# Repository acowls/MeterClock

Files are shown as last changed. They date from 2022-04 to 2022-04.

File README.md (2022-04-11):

# MeterClock

A clock displaying hour and minutes on two analog meters with a red LED matrix for time and date. Powered by an AVR Arduino and an RTC.

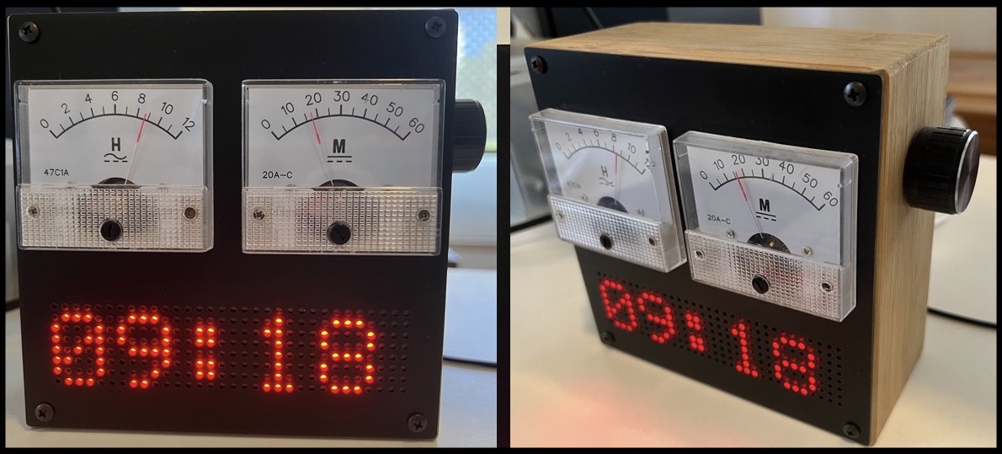
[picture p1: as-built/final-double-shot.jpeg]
final shot


## Parts List

+ Bamboo/Timber box without lid
+ Ardunino Nano (ATMega168)
+ milliamp meters x2
+ LED matrix modile 32 by 8 (4 module 8x8 LED matrix powered by MAX7221)
+ DS3231 module
+ PCB front panel
+ PCB inner meter panel x2 (one for hours, one for minutes)
+ Functional PCB
+ Push button
+ Rotary Encoder, with knob
+ various small screws for mounting

### Tools Required

+ Soldering Iron
+ Solder
+ Saw for cutting timber
+ Screwdrivers
+ Hot Glue Gun
+ Drill

## Design

I wanted the overall product to have a retro vibe to provide some symmetry with the meters. I chose a bamboo housing (which isn't exactly retro - maybe wood panelling would be more so - but is readily available in many discount thrift shops near me). So with the outer material chosen I then needed to think about the front panelling. I took the decision early on to use EasyEDA as the schematic design tool and JLCPCB as the manufacturer. As part of that approach I decided to make the front panel out of a PCB. This could be made on a 3D printer instead. The inner panels, those that sit inside the meters, are also made from a white PCB with black lattering. I do like the precision of the white PCB. Alternatively these could be made with paper and produced on a standard laser printer and cut to fit. 

One of the use cases I had for the clock is to softly alert me every hour and half hour during the day. This is my cue that I might have to join a meeting or otherwise check my schedule. The code turns the LED matrix on each half hour during daytime. 

### Power

Power for the device is 5V from the micro-USB connector extent on the Ardunio Nano module. This also serves as the programming port for updating the code. The board was oriented so that the micro USB was accessible from the rear of the encolsure. 

### Interface

The rotary control is used for changing date and time. I chose this interface method since it is much smoother and nicer than clicking buttons and in my opinion more intuitive. The code isnt that much more complex and I'd argue that the physcial build is simplified since one physcial encoder provides three inputs: up, down and click. The encoder has another advantage in mounting location. If you put buttons on the side of a device you need to hold the top of the device while pressing the buttons otherwise the device slips around. In practice this means using your other hand or using the thumb to hold it down while the fingers do the clicking. The one button I put on the device i mounted towards the top on the back panel. For usage you would look at the front of the device and then put your hand over the top and with your palm resting on the device click / hold the button down to enter the mode for setting the time and date.

Using 7H by 5W characters the 32x8 LED matrix provides enough space for the display for 5 characters at a time. This is sufficient for year, date and time. I originally intended to have animated use of the matrix (scrolling) but the max storage space of the ATMega168 was full.

### Improvements

I hit the limits of functionality that I could pack inside of the Arduino Nano ( an ATMega168 with 16k storage). With two buttons and a rotary dial plus the outputs of the 32x8 matrix and the two analgoue meters there is a fair bit more functionality I wanted to write but simply ran out of bytes of storage in the Arduino Nano to do so. Any improvements should look at using a controller with more storage space. 

### Schematic

The circuit is built around the Arduino Nano with debouncing circuitry for the mechanical inputs of the buttons & encoder. There are interfaces to the LED matrix module and the RTC module. 

The meters operate through a 2.7k ohm resister to ground and two pins on the Arudino supply the analog output (aka a variable voltage) to move the needles from 0 to 12 for the hours and 0 to 60 for the minutes.

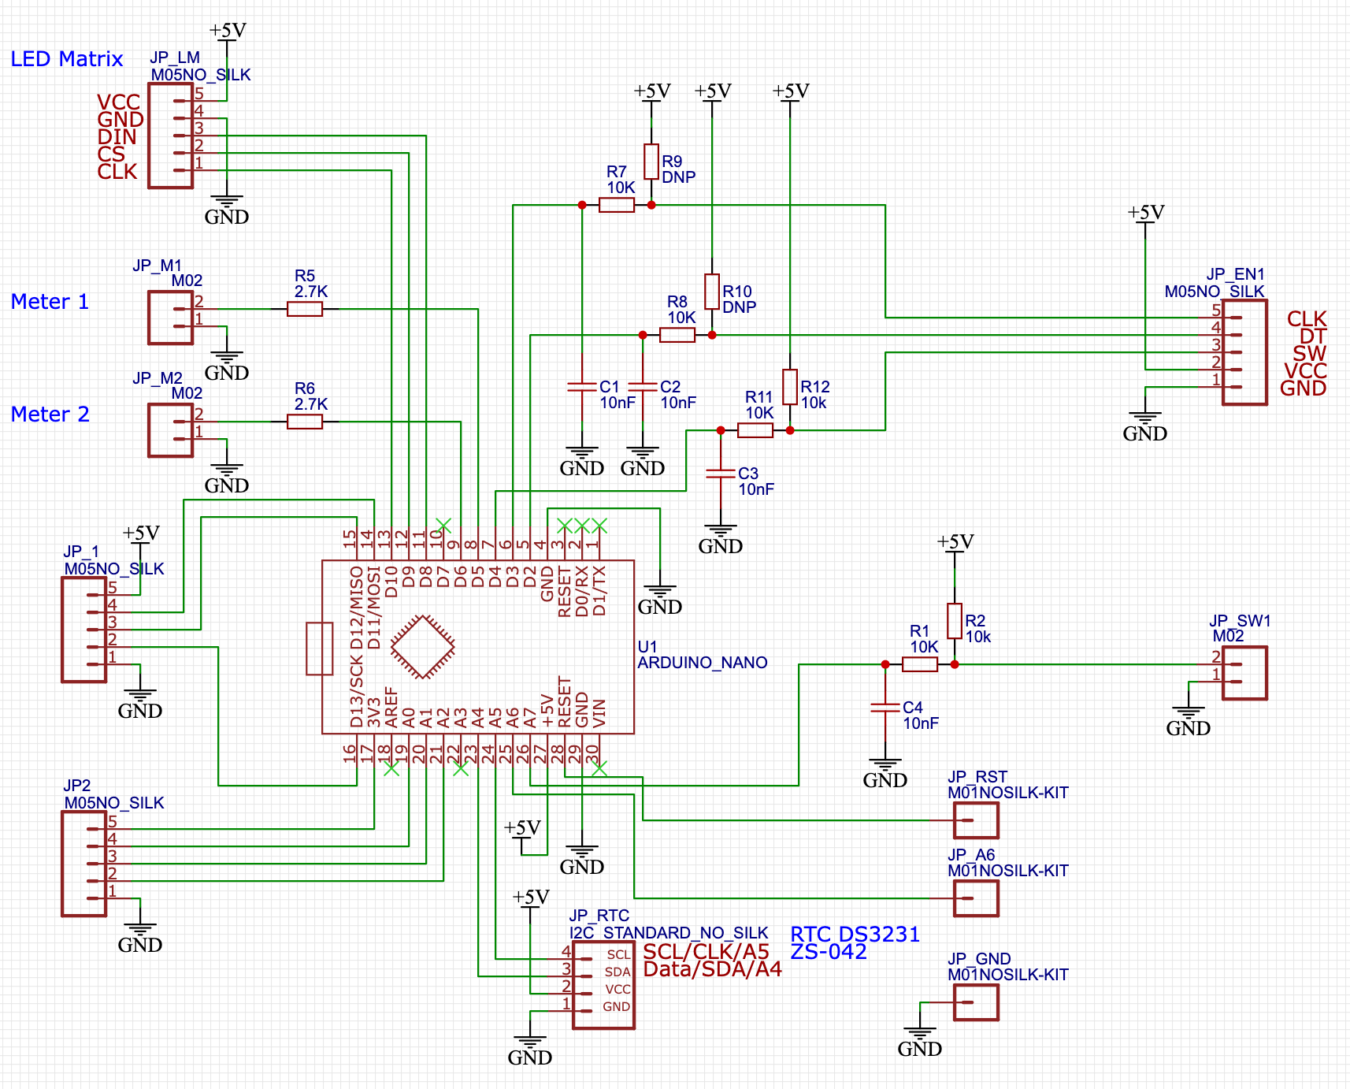
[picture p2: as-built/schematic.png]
schematic


## Software

### Library List

+ [Notched Shaft Encoder v1.0.0](https://github.com/lesterlo/Notched-Shaft-Encoder) - Monitor the postion and clickable button status from a notched shaft encoder
+ [RTCLib by NeiroNx v1.6](https://github.com/NeiroNx/RTCLib) - A library that makes interfacing DS1302, DS1307, DS3231, PCF8583, PCF8563, RTC_Millis Real Time Clock modules easy.
+ [AceButton v1.6.1](https://github.com/bxparks/AceButton) - An adjustable, compact, event-driven button library that handles debouncing and dispatches events to a user-defined event handler.

## As-Built

### External

Inside of the Meter Clock there is room for Arduino Nano, DS3231 module, connectors for LED matrix 32x8 using MAX7221 and debouncing connection for two switches and one encoder.

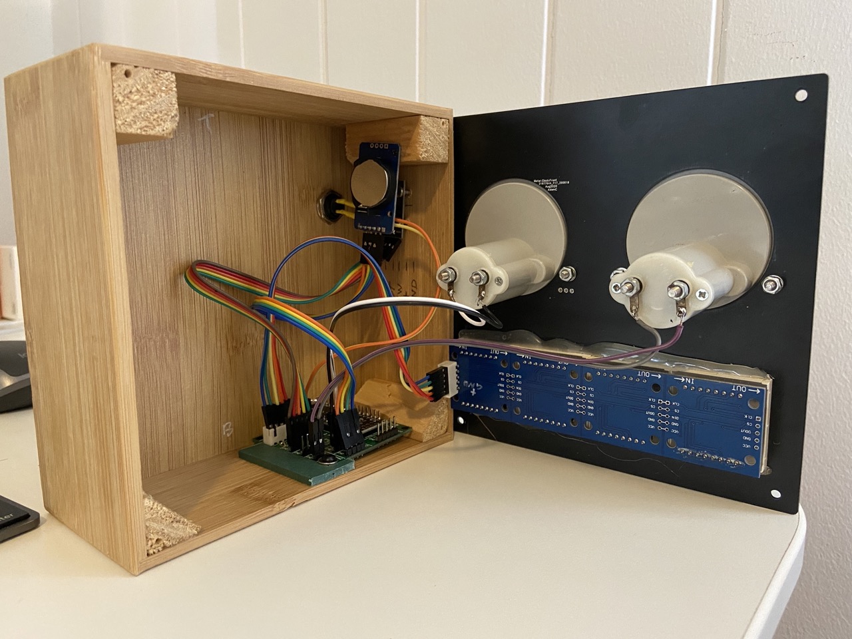
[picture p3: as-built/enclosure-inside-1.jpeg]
inside of the meter clock


### PCB Mainboard 

This is the PCB inside of the meter clock. It has a spot to mount the Arduino Nano and the RTC. The remainder of the board has connectors to the display (led matrix) and the RC filtered inputs (encoder and push button). 

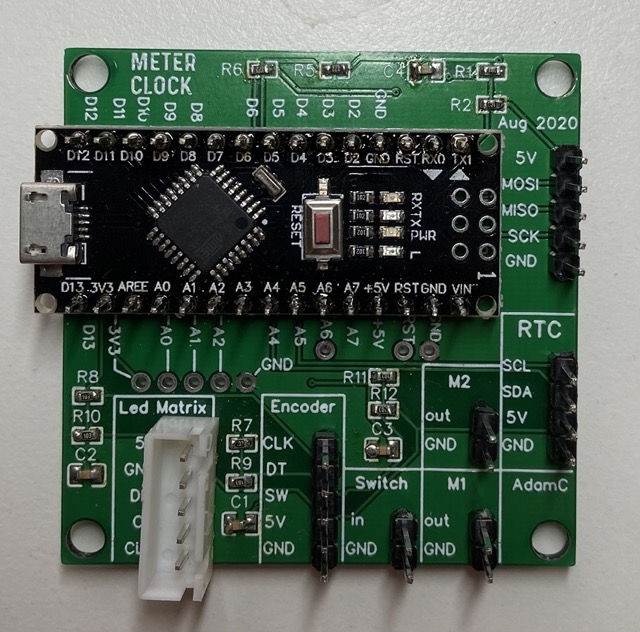
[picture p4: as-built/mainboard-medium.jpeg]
mainboard with adruino nano mounted


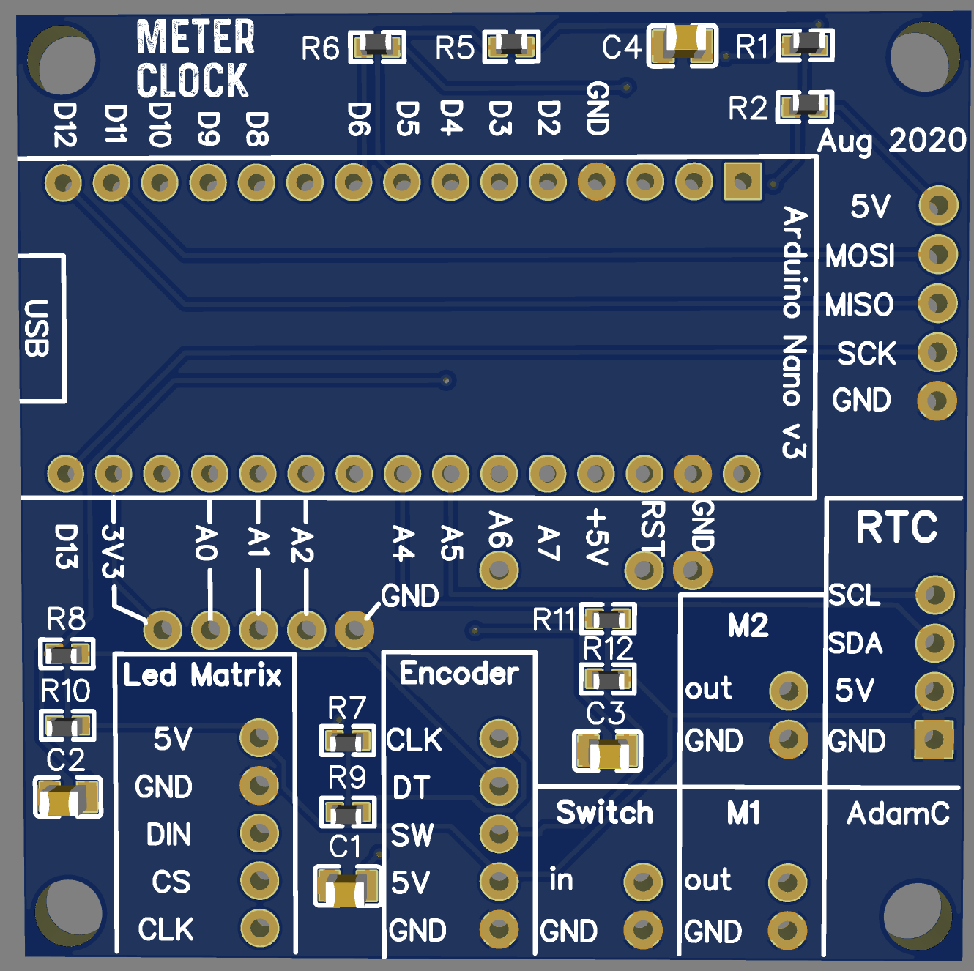
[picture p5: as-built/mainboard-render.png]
mainboard


### PCB Inside Meter

MeterClockInner - The inside of the analogue meters that shows graduations from 0 to 12 for hours and on the reverse side, from 0 to 60 for minutes.
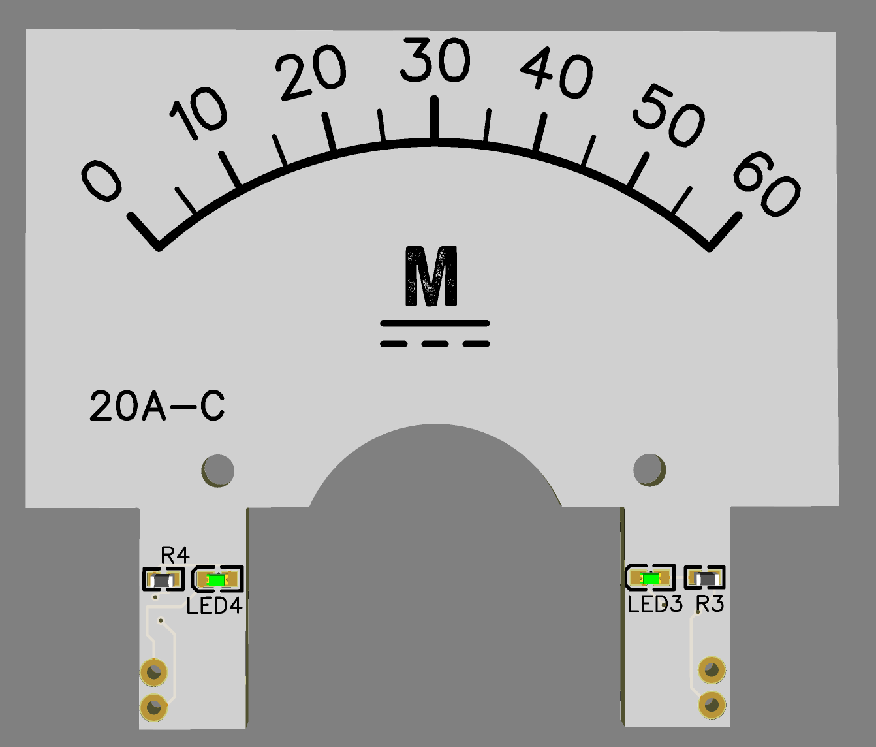
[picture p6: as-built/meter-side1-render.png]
inside pcb


+ [oshwlab MeterClockInner](https://oshwlab.com/adamc/meterclockinner)
+ [EasyEDA MeterClockInner](https://easyeda.com/editor#id=60065c9caff1483fb72fd92636a5c24b)

### PCB Front Face

to do

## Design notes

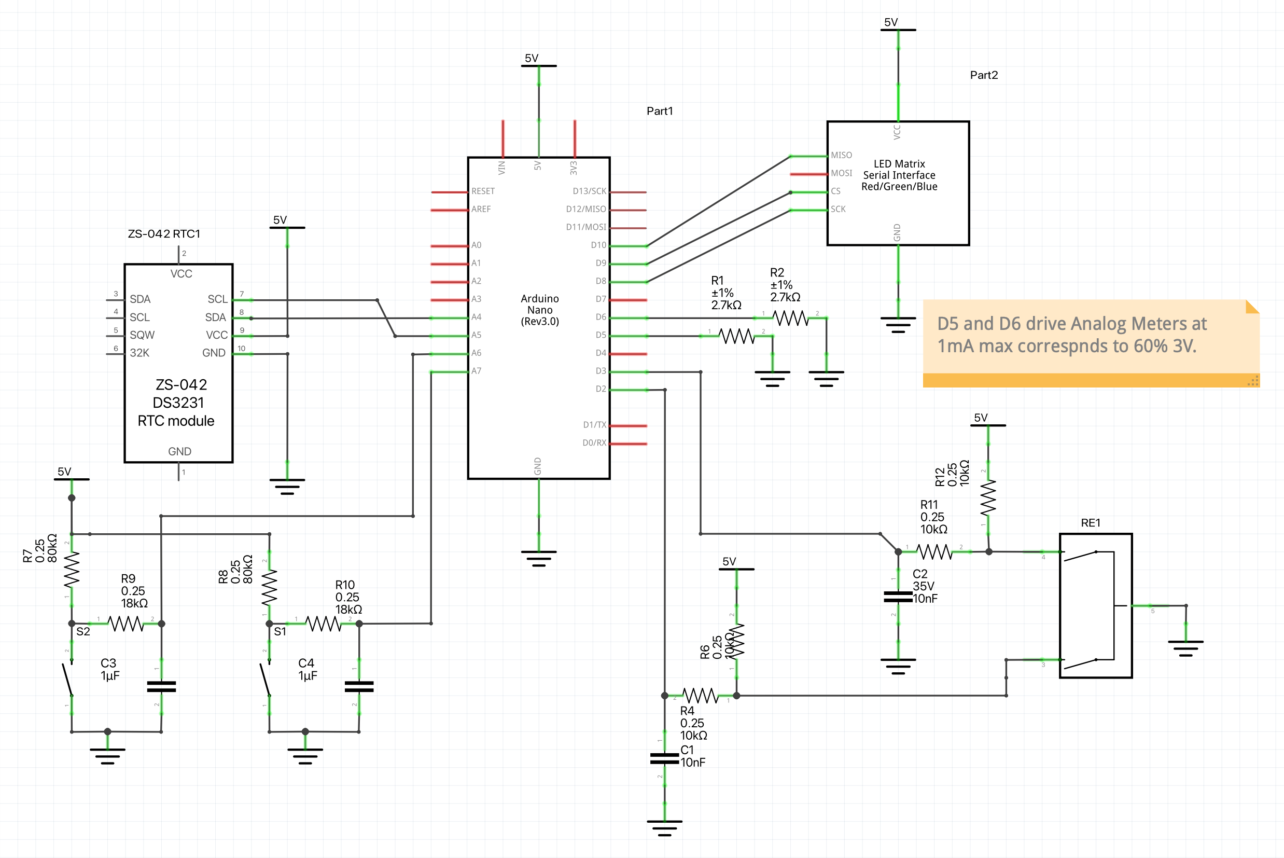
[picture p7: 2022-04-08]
as-built/fritzing-schematic.png

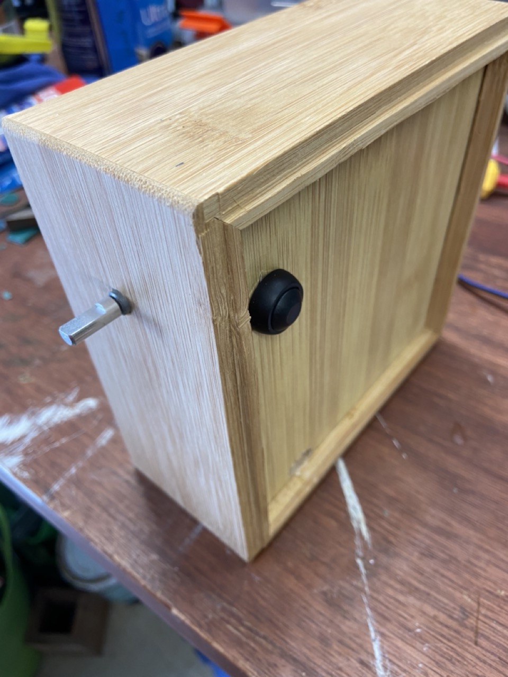
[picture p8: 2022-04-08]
as-built/enclosure-rear-2.jpeg

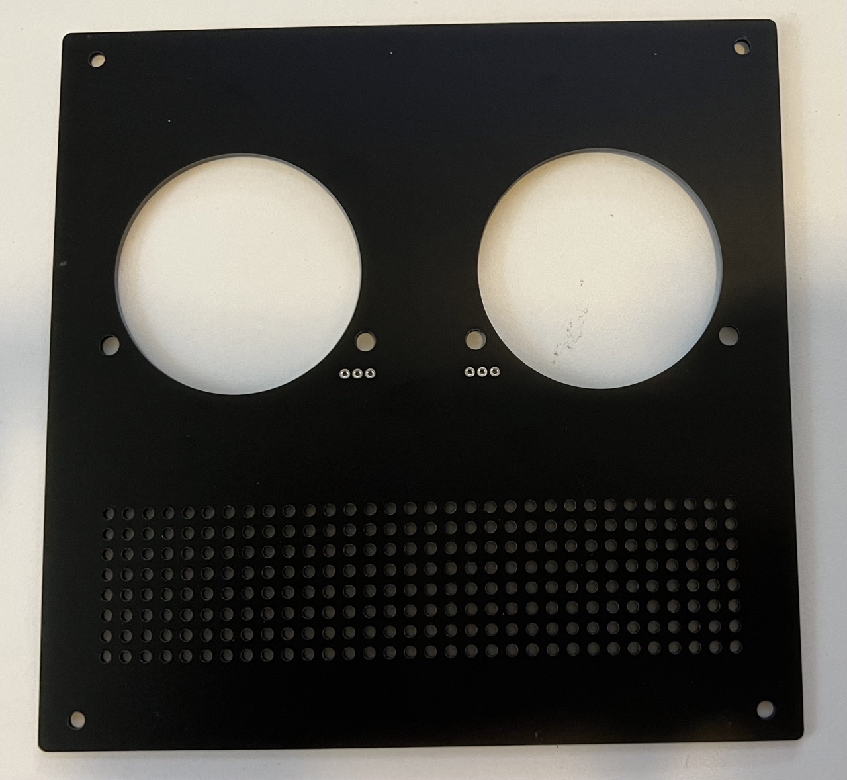
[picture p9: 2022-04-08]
as-built/front-panel.jpeg

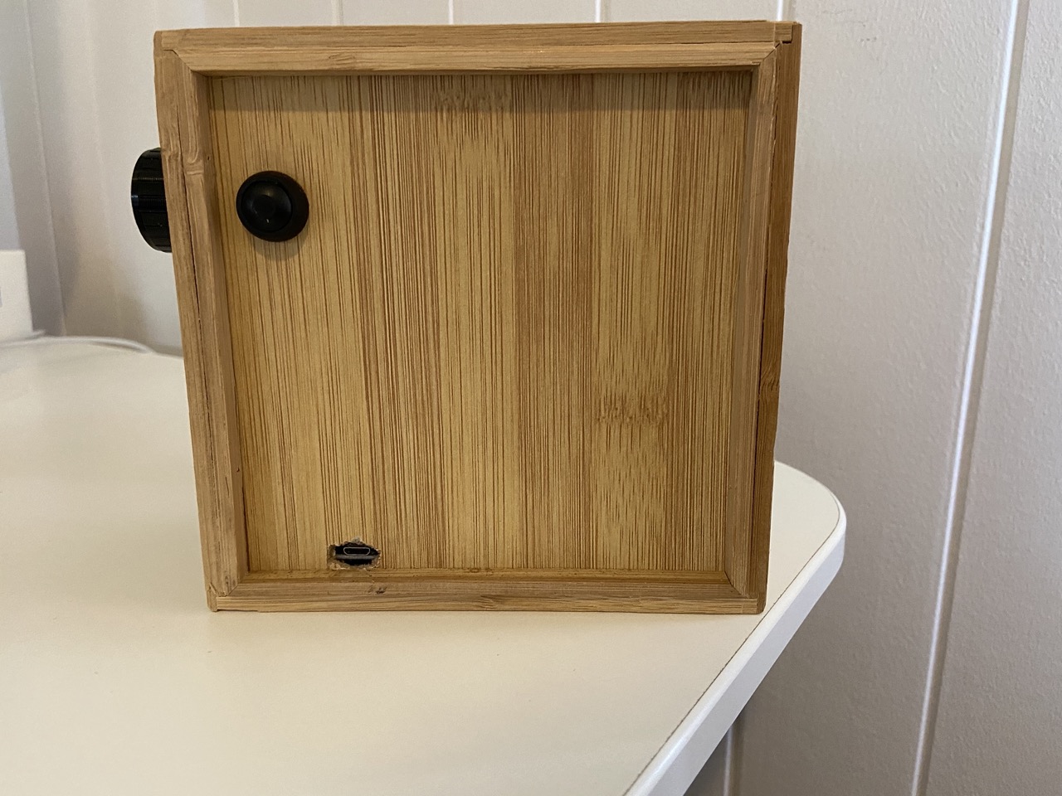
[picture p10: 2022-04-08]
as-built/enclosure-rear-1.jpeg

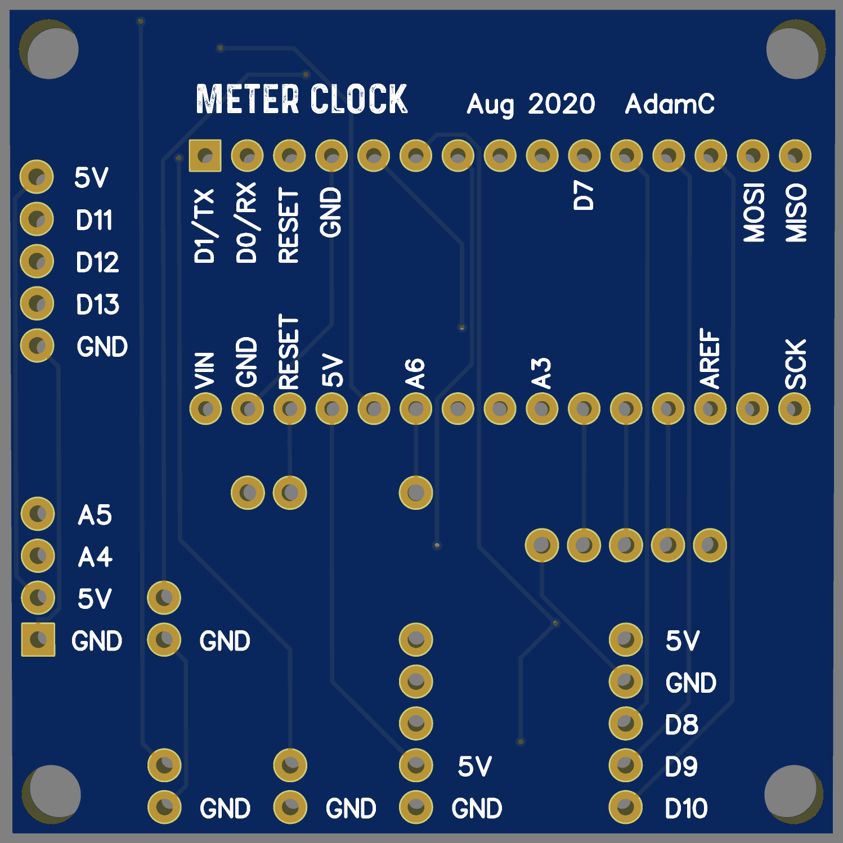
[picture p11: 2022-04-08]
as-built/mainboard-rear-render.png

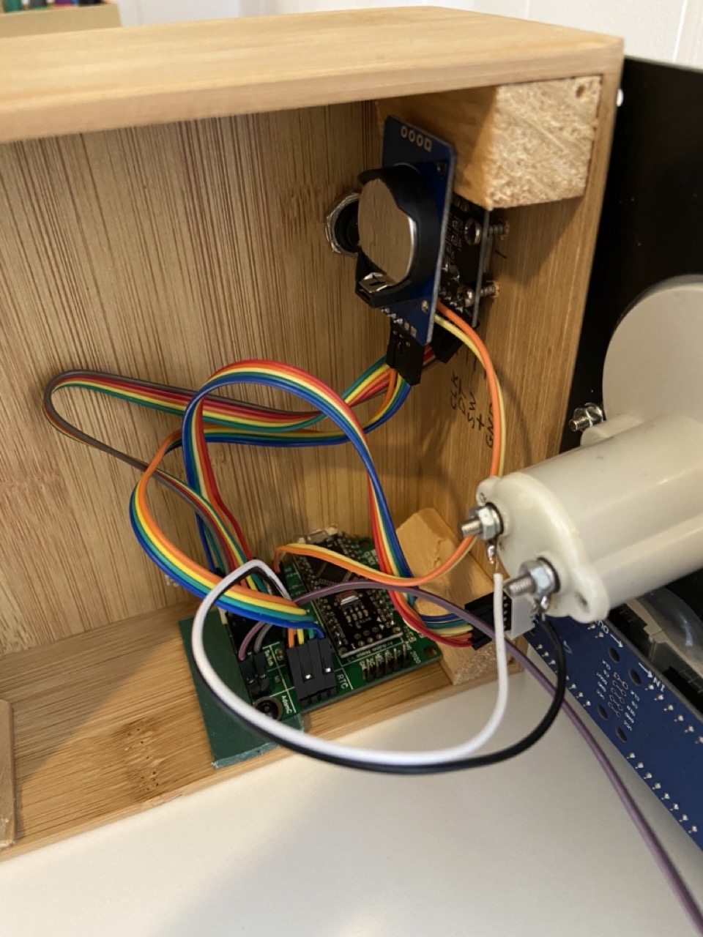
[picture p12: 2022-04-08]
as-built/enclosure-inside-2.jpeg

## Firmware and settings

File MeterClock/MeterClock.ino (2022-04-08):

#include "LedMatrixControlEx.h"
#include "RTClib.h" // https://github.com/NeiroNx/RTCLib/blob/master/src/RTClib.h
#include <NSEncoder.h>
#include <AceButton.h>
using namespace ace_button;
// fancy text from https://textfancy.com/multiline-text-art/

///// INPUTS
// Encoder with push button  switch
// Pushbutton Switch

///// OUTPUTS
// 2x Analog Meters showing Hours and Minutes
// 4x LEDs for back lighting those two Meters
// 32x8 LED matrix for display of characters and words

///// FEATUREs
// Backlighting on (for night time)
// Meter Time always on
// Toggle through timezones (no daylight saving?)
//   - Date programmed through USB
// Set Hour
// Set Minutes 

///// General Approach
// B2-LP Long Hold back button #2 to enter time / date setting mode.
//  Hour Set  B1-C > Minute Set 1C > Year Set 1C> Month Set
//  2C > cancel ... go to display 
//  2L > save new date and time 


// RTC 3231
// Defaults to:
// SCL/CLK  on A5 (pin 24)
// SCA/DATA on A4 (pin 23)
RTC_DS3231 rtc;

// NSEncoder (S1, S2, # pulses / notch)
// CLK = D3 (pin 6)
// CLK = D2 (pin 5)
NSEncoder control(2, 3, 2);

const byte MODULE_COUNT = 4;
// LedMatrixControl ( DIN, CLK, CS, # of 8x8s )
// DIN = D8 (pin 11) 
// CS  = D9 (pin 12)
// CLK = D10 (pin 13)
LedMatrixControl lc = LedMatrixControl(8, 10, 9, MODULE_COUNT);

// Diplay Meters
#define METER_HOUR   5
#define METER_MINUTE 6

// Buttons
// D4 (pin 7)
// A2 (pin 2?)
#define BUTTON1_PIN 4
#define BUTTON2_PIN A2

AceButton button1(BUTTON1_PIN);
AceButton button2(BUTTON2_PIN);

void handleEvent(AceButton*, uint8_t, uint8_t);

int currentPosInFrameBuffer = 0;
int controlPosition  = 0;

// Milliseconds between frames in animation effects
#define QUICK_STEP 15
// Maximum number of characters in the buffer
#define MAX_CHARS_IN_BUFFER 10

void setup(){
  delay(1000); // some boards reboot twice
  Serial.begin(115200);

  // Buttons use the built-in pull up register.
  pinMode(BUTTON1_PIN, INPUT_PULLUP);
  pinMode(BUTTON2_PIN, INPUT_PULLUP);

  ButtonConfig* buttonConfig = ButtonConfig::getSystemButtonConfig();
  buttonConfig->setEventHandler(handleEvent);
  buttonConfig->setEventHandler(handleEvent);
  buttonConfig->setFeature(ButtonConfig::kFeatureClick);
  buttonConfig->setFeature(ButtonConfig::kFeatureDoubleClick);
  buttonConfig->setFeature(ButtonConfig::kFeatureLongPress);
  
  // set the intensity
  lc.setIntensity(3);
  lc.shutdown(0);

    if (! rtc.begin()) {
    Serial.println(F("Couldn't find RTC"));
    Serial.flush();
    abort();
  }

  if (rtc.lostPower()) {
    Serial.println(F("RTC lost power, let's set the time!"));
    // When time needs to be set on a new device, or after a power loss, the
    // following line sets the RTC to the date & time this sketch was compiled
    rtc.adjust(DateTime(F(__DATE__), F(__TIME__)));
    // This line sets the RTC with an explicit date & time, for example to set
    // 15th Oct 2020 - 12:45:55
    // rtc.adjust(DateTime(2020, 10, 15, 12, 40, 55));
  }

  welcome_sequence();
}

// counter of how many times through the loop since lat mode change or input
uint16_t tick = 0;

void loop() {
  int newPos;
  
  if (control.get_Position(newPos)) {
    char posfmt[8];
    snprintf(posfmt, 8, "%d", newPos);
    Serial.println(posfmt);

    // reset the tick on input
    tick = 0;

    // call the correct handler for each event type
    if (newPos - controlPosition > 0) {
      if (handle_encoder_down(controlPosition, newPos))
        controlPosition = newPos;
      }
    else {
      if (handle_encoder_up(controlPosition, newPos))
        controlPosition = newPos;        
      }
    lc.updateDisplay();    
  }
  button1.check();
  button2.check();

  doTimer(tick);
  tick = tick + 1;
  doDisplay();
  doWakeEachHalfHour();
  delay(20);

}


/*
** The event handler for both buttons.
*/
void handleEvent(AceButton* button, uint8_t eventType, uint8_t buttonState) {
    switch (eventType) {
      case AceButton::kEventClicked:
        Serial.print(F("Click on Button "));
        if (button->getPin() == BUTTON1_PIN) {
          Serial.println(F("1 encoder button")); 
          handle_button_click();
        }
        else {
          Serial.println(F("2 rear button")); 
          handle_button_rear_click();
        }
        // reset the tick on input
        tick = 0;        
        break;

      // LONG PRESS BUTTON 1  
      case AceButton::kEventLongPressed:
        Serial.print(F("Long Press on Button "));       
        
        if (button->getPin() == BUTTON1_PIN) {
          Serial.println(F("1 encoder button")); 
          handle_button_longpress();
        }
        else {
          Serial.println(F("2 rear button")); 
          handle_button_rear_longpress();
        }
        // reset the tick on input
        tick = 0;
        break;
    }
}

//      *************************
//          M O D E   B I T s
//      *************************
#define MODE_POWERUP       0x4000

#define MODE_DISPLAY       0x0100 // mask for the following :-
#define MODE_DISPLAY_HOMI  0x0101  // hours and minutes
#define MODE_DISPLAY_DATE  0x0102  // Month/Day, eg: 30/11
#define MODE_DISPLAY_YEAR  0x0104  // year,      eg: 2020
#define MODE_DISPLAY_SLEEP 0x0180  // display off

#define MODE_SET_DT        0x0200 // mask for the following :-
#define MODE_SET_DT_HOUR   0x0201
#define MODE_SET_DT_MIN    0x0202
#define MODE_SET_DT_YEAR   0x0204
#define MODE_SET_DT_MON    0x0208
#define MODE_SET_DT_DAY    0x0210

uint16_t master_mode = MODE_POWERUP;
#define ISMODE(m) (master_mode & m) == m

const TimeSpan oneDay =   TimeSpan(1, 0, 0, 0);
const TimeSpan oneHour =  TimeSpan(0, 1, 0, 0);
const TimeSpan oneMin =   TimeSpan(0, 0, 1, 0);

DateTime editableDateTime;

/*
 * set the MODE
 * use this function instead of attempting to set mode variable directly. 
 * This will reset tick counter on a mode change.
 */
void setMode(uint16_t newMode) {
  if (master_mode != newMode) {
    Serial.print(F("setMode 0x"));
    Serial.print(master_mode, HEX);
    Serial.print(F("  to  0x"));
    Serial.println(newMode, HEX);    
    master_mode = newMode;
    // reset tick counter back to zero 
    tick = 0;
  }
}

/*
 * 
 *   o-o   o-O-o  o-o  o--o  o      O  o   o 
 *   |  \    |   |     |   | |     / \  \ /  
 *   |   O   |    o-o  O--o  |    o---o  O   
 *   |  /    |       | |     |    |   |  |   
 *   o-o   o-O-o o--o  o     O---oo   o  o   
 *                                       
 * do DISPLAY
 * the correct thing based on the current mode.
 */
void doDisplay() {
  char textbuf[8];

  if (ISMODE(MODE_DISPLAY)) {
    DateTime now = rtc.now();

    setMeters(now.hour(), now.minute());
    
    if (ISMODE(MODE_DISPLAY_SLEEP)) {
      lc.clearDisplay();
      // exit without an update
      return;
    }
    else if (ISMODE(MODE_DISPLAY_HOMI))
      snprintf(textbuf, 8, "%02d:%02d", now.hour(), now.minute()); 
    else if (ISMODE(MODE_DISPLAY_DATE))
      snprintf(textbuf, 8, "%02d/%02d", now.day(), now.month()); 
    else if (ISMODE(MODE_DISPLAY_YEAR))
      snprintf(textbuf, 8, "%04d", now.year());
  }
  else if (ISMODE(MODE_SET_DT_HOUR)) {
    if (((tick / 20) % 2) == 0)
      snprintf(textbuf, 8, "%02d:%02d", editableDateTime.hour(), editableDateTime.minute());     
    else
      snprintf(textbuf, 8, "  :%02d", editableDateTime.minute());
    setMeters(editableDateTime.hour(), editableDateTime.minute());         
  }
  else if (ISMODE(MODE_SET_DT_MIN)) {
    if (((tick / 20) % 2) == 0)
      snprintf(textbuf, 8, "%02d:%02d", editableDateTime.hour(), editableDateTime.minute());     
    else
      snprintf(textbuf, 8, "%02d:  ", editableDateTime.hour());      
    setMeters(editableDateTime.hour(), editableDateTime.minute()); 
    }
  else if (ISMODE(MODE_SET_DT_DAY)) {
    if (((tick / 20) % 2) == 0)
      snprintf(textbuf, 8, "%2d/%02d", editableDateTime.day(), editableDateTime.month());     
    else
      snprintf(textbuf, 8, "  /%02d", editableDateTime.month());      
  }   
  else if (ISMODE(MODE_SET_DT_MON)) {
    if (((tick / 20) % 2) == 0)
      snprintf(textbuf, 8, "%2d/%02d", editableDateTime.day(), editableDateTime.month());     
    else
      snprintf(textbuf, 8, "%2d/  ", editableDateTime.day());      
  }
  else if (ISMODE(MODE_SET_DT_YEAR)) {
    snprintf(textbuf, 8, "Y%04d", editableDateTime.year());      
    
  }
    
  putWordInBuffer(textbuf);
  lc.updateDisplay();     
}


void doWakeEachHalfHour() {
  // wake display on the hour every hour
  if (ISMODE(MODE_DISPLAY_SLEEP)) {
    DateTime now = rtc.now();
    if (now.second() == 0 && (now.minute() == 0 || now.minute() == 30)) {
      setMode(MODE_DISPLAY_HOMI);
    }
  }
}
/**
 *   ___         __  __  
 *    |  | |\/| |_  |__) 
 *    |  | |  | |__ | \  
 *                   
 *   Actions taken based on how many times through the loop we have traversed 
 */
int doTimer(uint16_t ticks)
{
  // check if in POWERUP explicitly 
  if (ISMODE(MODE_POWERUP)) {
    if (ticks > 100)
      setMode(MODE_DISPLAY_HOMI);
  }
  // screen idle time
  else if (ISMODE(MODE_DISPLAY)) {
    if (ticks > 500)
      setMode(MODE_DISPLAY_SLEEP);
    }
  // timeout on setting the date and time
  else if (ISMODE(MODE_SET_DT)) {
    if (ticks > 500)
      setMode(MODE_DISPLAY_HOMI);
  }
}


/*
 *  __  ____ __   __      __  _  _ ___ ___  __  _  _    _     __  _  _  ___     __   __  ____  ___  ___
 * |__/ |___|__| |__/    |__] |  |  |   |  |  | |\ |    |    |  | |\ | | __    |__] |__/ |___ [__  [__ 
 * |  \ |___|  | |  \    |__] |__|  |   |  |__| | \|    |___ |__| | \| |__]    |    |  \ |___ ___] ___]
 */
void handle_button_rear_longpress() {
  char textbuf[8];
  snprintf(textbuf, 8, "hour"); 
      
  if (ISMODE(MODE_DISPLAY) || ISMODE(MODE_POWERUP)) {
    // enter date and time setting mode
    editableDateTime = rtc.now();
    setMode(MODE_SET_DT_HOUR);

    putWordInBuffer("set");
    lc.updateDisplay();
    delay(QUICK_STEP);
    putWordInBuffer("hour");
    lc.updateDisplay();
    
  } 
  else if (ISMODE(MODE_SET_DT)) {
    // end date and time setting mode. 
    rtc.adjust(editableDateTime);
    setMode(MODE_DISPLAY_HOMI);
        
    Serial.print(F("adjustment done "));
    Serial.print(editableDateTime.year());
    Serial.print(F("-"));
    Serial.print(editableDateTime.month());
    Serial.print(F("-"));
    Serial.print(editableDateTime.day());
    Serial.print(F(" "));
    Serial.print(editableDateTime.hour());
    Serial.print(F("h "));
    Serial.print(editableDateTime.minute());
    Serial.println(F("m"));
  }
  else
  {
    Serial.print(F("mode 0x"));
    Serial.print(master_mode, HEX);
    Serial.println(F(" unhandled in handle_button_rear_longpress()"));
  }
}

/*
 *     __  _  _ ___ ___  __  _  _    _     __  _  _  ___     __   __  ____  ___  ___
 *    |__] |  |  |   |  |  | |\ |    |    |  | |\ | | __    |__] |__/ |___ [__  [__ 
 *    |__] |__|  |   |  |__| | \|    |___ |__| | \| |__]    |    |  \ |___ ___] ___]
 */
void handle_button_longpress() {
  Serial.print(F("mode 0x"));
  Serial.print(master_mode, HEX);
  Serial.println(F(" unhandled in handle_button_longpress()"));
}

/*
 * handle REAR BUTTON click
 */
void handle_button_rear_click() {
  //
  handle_button_click();
  /*
    Serial.print(F("mode 0x"));
    Serial.print(master_mode, HEX);
    Serial.println(F(" unhandled in handle_button_rear_click"));
  */
}

/*
 * handle BUTTON click
 */
void handle_button_click() {
  if (ISMODE(MODE_SET_DT_HOUR)) {
    setMode(MODE_SET_DT_MIN);
  }  
  else if (ISMODE(MODE_SET_DT_MIN)) {
    setMode(MODE_SET_DT_YEAR);
  } 
  else if (ISMODE(MODE_SET_DT_YEAR)) {
    setMode(MODE_SET_DT_MON);
  } 
  else if (ISMODE(MODE_SET_DT_MON)) {
    setMode(MODE_SET_DT_DAY);
  } 
  else if (ISMODE(MODE_SET_DT_DAY)) {
    setMode(MODE_SET_DT_HOUR);
  }
  else {
    Serial.print(F("mode 0x"));
    Serial.print(master_mode, HEX);
    Serial.println(F(" unhandled in handle_button_click()"));
  }
}
                                                                       
                                                                        

/**
 *  _____               _            __ __ _____ 
 * |   __|___ ___ ___ _| |___ ___   |  |  |  _  |
 * |   __|   |  _| . | . | -_|  _|  |  |  |   __|
 * |_____|_|_|___|___|___|___|_|    |_____|__|   
 *
 * Handle ENCODER UP 
 * return 1 to allow click up
 */
bool handle_encoder_up(int current, int proposed) {
    /*char posfmt[8];
    snprintf(posfmt, 8, "%xu%d",master_mode, proposed); 
    Serial.println(posfmt);
    */

  if (ISMODE(MODE_DISPLAY_SLEEP)) {
    setMode(MODE_DISPLAY_HOMI);    
  }
  else if (ISMODE(MODE_DISPLAY_HOMI)) {
    setMode(MODE_DISPLAY_YEAR);    
  }
  else if (ISMODE(MODE_DISPLAY_DATE)) {
    setMode(MODE_DISPLAY_HOMI);    
  }
  else if (ISMODE(MODE_DISPLAY_YEAR)) {
    setMode(MODE_DISPLAY_DATE);    
  }
  else if (ISMODE(MODE_SET_DT_HOUR)) {
    editableDateTime = editableDateTime + oneHour; 
  }
  else if (ISMODE(MODE_SET_DT_MIN)) {
    editableDateTime = editableDateTime + oneMin;
  }
  else if (ISMODE(MODE_SET_DT_DAY)) {
    editableDateTime = editableDateTime + oneDay;
  }   
  else if (ISMODE(MODE_SET_DT_MON)) {
    int newMonth = editableDateTime.month() + 1;
    editableDateTime = DateTime(editableDateTime.year(), newMonth == 13 ? 0 : newMonth, editableDateTime.day(), editableDateTime.hour(), editableDateTime.minute(), 0);
  }
  else if (ISMODE(MODE_SET_DT_YEAR)) {
    int year = editableDateTime.year();
    if (year < 2150)
      editableDateTime = DateTime(year + 1, editableDateTime.month(), editableDateTime.day(), editableDateTime.hour(), editableDateTime.minute(), 0);
  }   
  else
  {
    Serial.print(F("mode 0x"));
    Serial.print(master_mode, HEX);
    Serial.println(F(" unhandled in handle_encoder_up()"));
  }
        
  return true;
}


/**
 *  _____               _            ____  _____ _ _ _ _____ 
 * |   __|___ ___ ___ _| |___ ___   |    \|     | | | |   | |
 * |   __|   |  _| . | . | -_|  _|  |  |  |  |  | | | | | | |
 * |_____|_|_|___|___|___|___|_|    |____/|_____|_____|_|___|
 *                                                           
 * Handle ENCODER DOWN
 * return 1 to allow click down
 */
bool handle_encoder_down(int current, int proposed) {
    /*char posfmt[8];
    snprintf(posfmt, 8, "%xd%d",master_mode, proposed); 
    Serial.println(posfmt);
    */
    
  if (ISMODE(MODE_SET_DT_HOUR)) {
    editableDateTime = editableDateTime - oneHour;
    }
  else if (ISMODE(MODE_SET_DT_MIN)) {
    editableDateTime = editableDateTime - oneMin;
    }
  else if (ISMODE(MODE_SET_DT_DAY)) {
    editableDateTime = editableDateTime - oneDay;
    }    
  else if (ISMODE(MODE_SET_DT_MON)) {
    int newMonth = editableDateTime.month() - 1;
    editableDateTime = DateTime(editableDateTime.year(), newMonth == 0 ? 12 : newMonth, editableDateTime.day(), editableDateTime.hour(), editableDateTime.minute(), 0);
    }
  else if (ISMODE(MODE_SET_DT_YEAR)) {
    int year = editableDateTime.year();
    if (year > 2020)
      editableDateTime = DateTime(year - 1, editableDateTime.month(), editableDateTime.day(), editableDateTime.hour(), editableDateTime.minute(), 0);
    }    
  else if (ISMODE(MODE_DISPLAY_SLEEP)) {
    setMode(MODE_DISPLAY_HOMI);    
  }
  else if (ISMODE(MODE_DISPLAY_HOMI)) {
    setMode(MODE_DISPLAY_DATE);    
  }
  else if (ISMODE(MODE_DISPLAY_DATE)) {
    setMode(MODE_DISPLAY_YEAR);    
  }
  else if (ISMODE(MODE_DISPLAY_YEAR)) {
    setMode(MODE_DISPLAY_HOMI);    
  }
  else    
  {    
    Serial.print(F("mode 0x"));
    Serial.print(master_mode, HEX);
    Serial.println(F(" unhandled in handle_encoder_down()"));
  }
              
  return true;
}


/*
 * set the meter displays
 */
void setMeters(uint8_t hour, uint8_t minute) {
  // HOUR Needle    0 = 0, 140 == 12 (full extent)
  // Minute Needle  0 = 0, 68  == 30 (half extent)
  
  // special case where we leave it at the right hand extent of the hour 
  if (hour == 12 && minute == 0) {
    analogWrite(METER_HOUR, 12 * 140 / 12);
  }
  else if (hour > 12) 
  {
    analogWrite(METER_HOUR, (hour - 12)  * 140 / 12);
  }
  else {
    analogWrite(METER_HOUR, hour * 140 / 12);
  }
  // set minute
  analogWrite(METER_MINUTE, minute * 68 / 30);  
}


/*
 * Welcome Sequence
 */
void welcome_sequence(){
  putWordInBuffer("Hello");
  lc.updateDisplay();

  DateTime now = rtc.now();
  char timefmt[8];
  snprintf(timefmt, 8, "%02d:%02d", now.hour(), now.minute());
  putWordInUpperBuffer(timefmt);
  annimateLedMatrixDown(500, QUICK_STEP, 500);  
}

/**
 * Animate characters in buffer to the left - slide effect. 
 */
void annimateLedMatrixLeft(int preDelay, int stepDelay, int postDelay) {
  delay(preDelay);
  if (currentPosInFrameBuffer > MODULE_COUNT * 8 - 5) {
    for (int loop = 0; loop < 6; loop++) {
      lc.shiftLeftFrameBuffer();            
      delay(stepDelay);
      lc.updateDisplay();
    }
    delay(postDelay);
  }
}

/**
 * Animate from Upper to Display buffer - window wipe down effect.
 */
void annimateLedMatrixDown(int preDelay, int stepDelay, int postDelay) {
  delay(preDelay);
  for (int loop = 0; loop < 8; loop++) {
    delay(stepDelay);
    lc.shuffleDownFrameBuffer();            
    lc.updateDisplay();
  }
  delay(postDelay);
}

/**
 * Animate from Upper to Display buffer - window wipe up effect.
 */
void annimateLedMatrixUp(int preDelay, int stepDelay, int postDelay) {
  delay(preDelay);
  for (int loop = 0; loop < 8; loop++) {
    delay(stepDelay);
    lc.shuffleUpFrameBuffer();            
    lc.updateDisplay();
  }
  delay(postDelay);
}

/**
 * Put a word in the Upper buffer
 */
void putWordInUpperBuffer(char *theWord)
{
  lc.clearUpperFrameBuffer();
  int len = strlen(theWord);
  if (len < 0 || len > MAX_CHARS_IN_BUFFER)
     return;
    
  for (int i = 0; i < len; i++)
  {
    lc.drawCharInUpperFrameBuffer(i * 6, theWord[i]);
  }
}

/**
 * Put a word in the Lower buffer
 */
void putWordInLowerBuffer(char *theWord)
{
  lc.clearLowerFrameBuffer();
  int len = strlen(theWord);
  if (len < 0 || len > MAX_CHARS_IN_BUFFER)
     return;
    
  for (int i = 0; i < len; i++)
  {
    lc.drawCharInLowerFrameBuffer(i * 6, theWord[i]);
  }
}

/**
 * Put a word in to the main display buffer
 */
void putWordInBuffer(const char *theWord)
{
  lc.clearFrameBuffer();
  int len = strlen(theWord);
  if (len < 0 || len > MAX_CHARS_IN_BUFFER)
     return;
    
  for (int i = 0; i < len; i++)
  {
    lc.drawCharInFrameBuffer(i * 6, theWord[i]);
  }
}

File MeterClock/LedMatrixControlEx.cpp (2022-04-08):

#include "LedMatrixControlEx.h"

// these are the opcodes for the MAX7221 and MAX7219 - refer datasheet
#define OP_NOOP   0
#define OP_DIGIT0 1
#define OP_DIGIT1 2
#define OP_DIGIT2 3
#define OP_DIGIT3 4
#define OP_DIGIT4 5
#define OP_DIGIT5 6
#define OP_DIGIT6 7
#define OP_DIGIT7 8
#define OP_DECODEMODE  9
#define OP_INTENSITY   10
#define OP_SCANLIMIT   11
#define OP_SHUTDOWN    12
#define OP_DISPLAYTEST 15

#define BUFFER_MAIN 0
#define BUFFER_UPPER 1
#define BUFFER_LOWER 2

#include <stdarg.h>
void printout(const char *fmt, ...) {
  #if 0
  char buf[128]; // resulting string limited to 128 chars
  va_list args;
  va_start(args, fmt);
  vsnprintf(buf, 128, fmt, args);
  va_end(args);
  Serial.print(buf);
  #endif
}

LedMatrixControl::LedMatrixControl(int dataPin, int clkPin, int csPin, int numModules) 
{
    SPI_MOSI=dataPin;
    SPI_CLK=clkPin;
    SPI_CS=csPin;

    // always at most 8 matrix modules.
    if (numModules <= 0 || numModules > MAX_MAX_MODULES )
        numModules = MAX_MAX_MODULES;

    maxModules = numModules;
    pinMode(SPI_MOSI, OUTPUT);
    pinMode(SPI_CLK, OUTPUT);
    pinMode(SPI_CS, OUTPUT);
    digitalWrite(SPI_CS, HIGH);

    // turn any display 'testing' OFF by sending a zero 
    spiTransferToAll("DISPLAYTEST", OP_DISPLAYTEST, 0);
    // scanlimit is set to the maximum (value 7) which is for 8 "digits", where a digit is the 7-seg LED. <-- this is a bit confusing but trust me.
    spiTransferToAll("SCANLIMIT", OP_SCANLIMIT, 7);
    // for 8x8 LED matrix modules we want all decoding done by use as we are not dealing with 7-seg LEDs
    spiTransferToAll("DECODEMODE", OP_DECODEMODE, 0);
    // clear the display
    clearDisplay();
    // now we get out of shutdown-mode on startup
    spiTransferToAll("SHUTDOWN", OP_SHUTDOWN, 0);
}

int LedMatrixControl::getModuleCount() {
    return maxModules;
}

void LedMatrixControl::shutdown(bool b) 
{
    if (b)
      spiTransferToAll("SHUTDOWN", OP_SHUTDOWN, 0);
    else
      spiTransferToAll("SHUTDOWN", OP_SHUTDOWN, 1);
}

void LedMatrixControl::setIntensity(int intensity) 
{
    if (intensity >= 0 && intensity < 16) 
      spiTransferToAll("INTENSITY", OP_INTENSITY, intensity);
}

void LedMatrixControl::clearDisplay()
{
  for (int module = 0; module < maxModules; module++)
  {
    for (int row = 0; row <= 7; row++)
    {
      frame[BUFFER_MAIN][module][row] = 0;
    }
  }
  updateDisplay();
}

void LedMatrixControl::spiTransfer(int addr, volatile byte opcode, volatile byte data) 
{
  // fill with NOOPs first
  for (int module = 0; module < maxModules; module++)
  {
    spidata[module][0] = (byte)OP_NOOP;
    spidata[module][1] = (byte)0;
  }
  
  // put our module data into the array
  spidata[addr][0]=opcode;
  spidata[addr][1]=data;
  spiWrite("spiTransfer");
}   

void LedMatrixControl::spiTransferToAll(const char *op_name, volatile byte opcode, volatile byte data) 
{
  for (int module = 0; module < maxModules; module++)
  {
    spidata[module][0] = opcode;
    spidata[module][1] = data;
  }
  spiWrite(op_name);
}

void LedMatrixControl::dumpFrameBuffer()
{
  for (byte row = 1; row <= 7; row++)
  {  
    for (int module = 0; module < maxModules; module++)
    {
      printout("0x%02x ", frame[BUFFER_MAIN][module][row]);
    }
    printout("\n");
  }
}

void LedMatrixControl::dumpLedMatrix()
{
  for (byte row = 1; row <= 7; row++)
  {  
    for (int module = 0; module < maxModules; module++)
    {
      for (int abit = 0x80; abit > 0; abit = abit >> 1)
      {
        printout("%c", frame[BUFFER_MAIN][module][row] & abit ? 'X' : '.');
      }
      printout(" ");
    }
    printout("\n");
  }
}


void LedMatrixControl::shiftLeftFrameBuffer()
{
  for (byte row = 1; row <= 7; row++)
    {
    for (int module = 0; module < maxModules; module++)
    {
      // ADAM it is left shiting not right need to mask 0x80 !!!!
      frame[BUFFER_MAIN][module][row] = (frame[BUFFER_MAIN][module][row] << 1) & 0xfe;
      if (frame[BUFFER_MAIN][module + 1][row] >> 7 == 0x01)
      {
        //printout("shiftLeftFrameBuffer m=%d,r=%d frame=0x%x carried=0x%x from m=%d\n", module, row, frame[module][row], 
        //  frame[module + 1][row], module + 1);
        frame[BUFFER_MAIN][module][row] |= 0x01;        
      }
    }
  }
}

/**
 * Shuffles from the upper buffer to the visible buffer - just the last line. call 7 times to complete shuffle
 */
void LedMatrixControl::shuffleDownFrameBuffer()
{
  for (int module = 0; module < maxModules; module++) {
    for (byte row = 7; row >0; row--) {
      // copy the one just above
      frame[BUFFER_MAIN][module][row] = frame[BUFFER_MAIN][module][row - 1];
      }
    // copy down the upper frame buffer last item to the first item one
    frame[BUFFER_MAIN][module][0] = frame[BUFFER_UPPER][module][7];
    
    for (byte row = 7; row >0; row--) {
      frame[BUFFER_UPPER][module][row] = frame[BUFFER_UPPER][module][row - 1];
      }    
    // clear the top of the upper buffer
    frame[BUFFER_UPPER][module][0] = 0x00;      
   }
}

/**
 * Shuffles from the lower buffer to the visible buffer - just the top line. call 7 times to complete shuffle
 */
void LedMatrixControl::shuffleUpFrameBuffer()
{
  for (int module = 0; module < maxModules; module++) {
    for (byte row = 0; row <7; row++) {
      // copy the one just below
      frame[BUFFER_MAIN][module][row] = frame[BUFFER_MAIN][module][row + 1];
      }
    // copy up the lower frame buffer first item to the last item one
    frame[BUFFER_MAIN][module][7] = frame[BUFFER_LOWER][module][0];
    
    for (byte row = 0; row <7; row++) {
      frame[BUFFER_LOWER][module][row] = frame[BUFFER_LOWER][module][row + 1];
      }    
    // clear the bottom of the lower buffer
    frame[BUFFER_LOWER][module][7] = 0x00;      
   }
}

void LedMatrixControl::drawCharInFrameBuffer(int x, char character)
{
  drawCharInOneFrameBuffer(BUFFER_MAIN, x, character);
}
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

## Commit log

2021-11-03 Working code base
    initial commit of Arduino working code base
2022-04-08 Added readme and as-built images
    [MeterClock-fritzing-schematic.fzz]
